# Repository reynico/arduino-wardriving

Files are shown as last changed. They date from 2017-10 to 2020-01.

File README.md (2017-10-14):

# ESP8266 based Arduino wardriving

## What is this?
A simple/cheap hardware + software setup to do wardriving trips and store as much information as we can on a SD card, using a small Arduino box.
Part of the datalogging code stolen from [Sparkfun](https://learn.sparkfun.com/tutorials/gps-logger-shield-hookup-guide/example-sketch-gps-serial-passthrough) guys

## What do we need?
* [$2.98](http://www.ebay.com/itm/222612803340) ESP8266 board (NodeMCU v3 works great)
* [$0.99](http://www.ebay.com/itm/261720518170) Arduino SD Card shield + SD card (a 10 minute trip could generate a 250KB file)
* [$4.21](http://www.ebay.com/itm/142233250679) Blox GY-NEO6MV2 GPS board
* [$3.07](http://www.ebay.com/itm/222311849398) HD44780 i2c LCD screen
* [$1.25](http://www.ebay.com/itm/332023213881) USB powerbank

## What does this do?
* Checks for a working SD Card
* Waits for GPS signal
* Collects all WiFi signals on 2.4Ghz on every (configurable) GPS sample
* Stores this information as a CSV file

## What does this doesn't do?
* This doesn't capture pcap files due power limitations
* This doesn't attack any network

## What does this need?
~~* A better/sorted insertion on CSV files to get rid of duplicate network entries~~ Fixed on d88815b43919bbf54e27a75a84c77be891900372
* Fix some race conditions
* A PCB design that I'm working on
* A better antenna for GPS and WiFi, that will help to speed up satellite lock-up and enlarge WiFi coverage

## What do you need to configure?
Nothing, but you can:
* Setup CS pin for SD card module on *ARDUINO_USD_CS* variable
* Change log file prefix and suffix on *LOG_FILE_PREFIX* and *LOG_FILE_SUFFIX*
* Remove or add columns to CSV datalog on *log_col_names*
* Define GPS log rate time on *LOG_RATE* (milliseconds)
* Define GPS TX/RX pins on *ARDUINO_GPS_RX* and *ARDUINO_GPS_TX*

## Electric setup
Electric setup has nothing special, there is a Fritzing diagram attached as well as a breadboard view of the setup


## Working examples
I did a small walking trip around my neighborhood, and put the collected data on a [Google MyMaps](https://www.google.com/maps/d/u/0/viewer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). Note that MyMaps has a limitation of 2000 entries of each CSV (or XML) file. I will try using Open street maps.


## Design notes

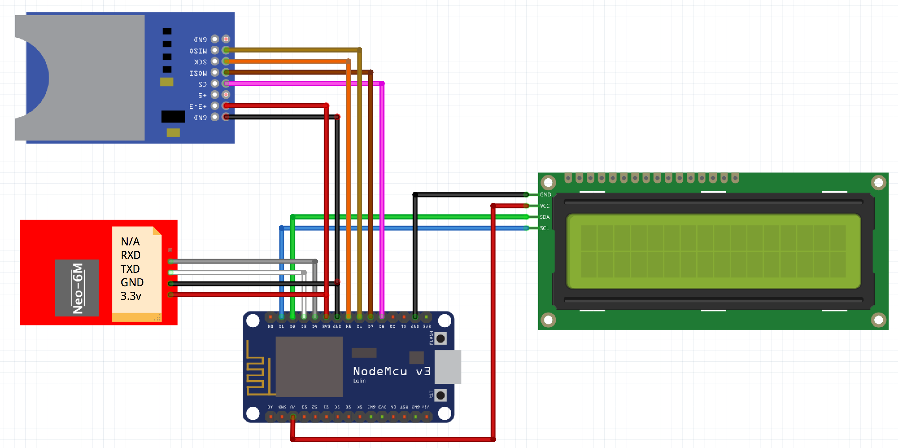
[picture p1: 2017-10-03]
breadboard.png

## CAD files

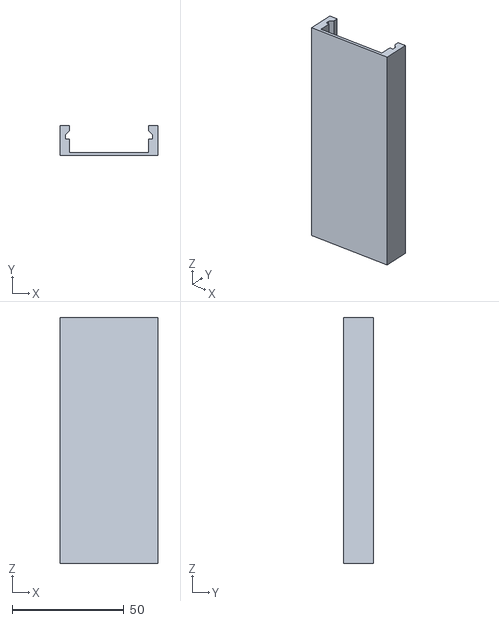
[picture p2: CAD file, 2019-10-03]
printed_case/Wardriving Case - B.stl
43.9 x 13.6 x 110.0

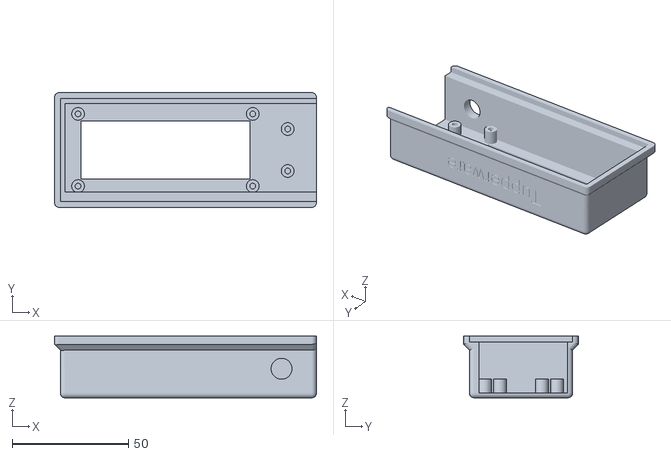
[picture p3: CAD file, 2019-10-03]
printed_case/Wardriving Case - A.stl
112.5 x 49.3 x 26.5

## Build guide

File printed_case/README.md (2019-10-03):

# 3D printed case
[Matias](https://instagram.com/punch.efi) designed and printed this case for the project.

## Finished product
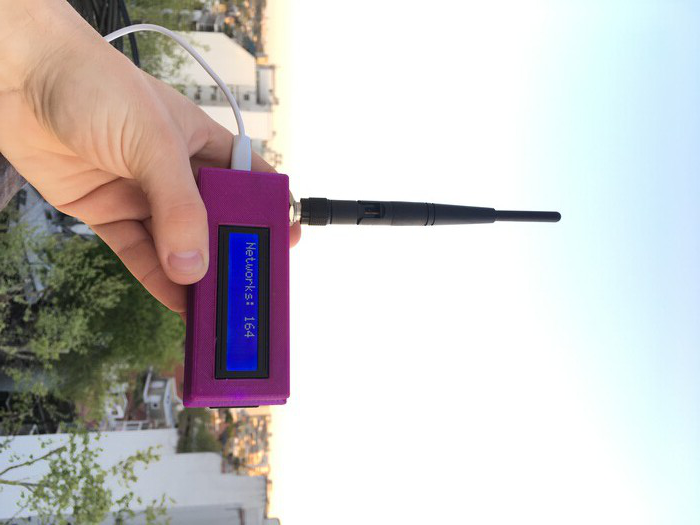
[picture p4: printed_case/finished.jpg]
finished


## Assembly view
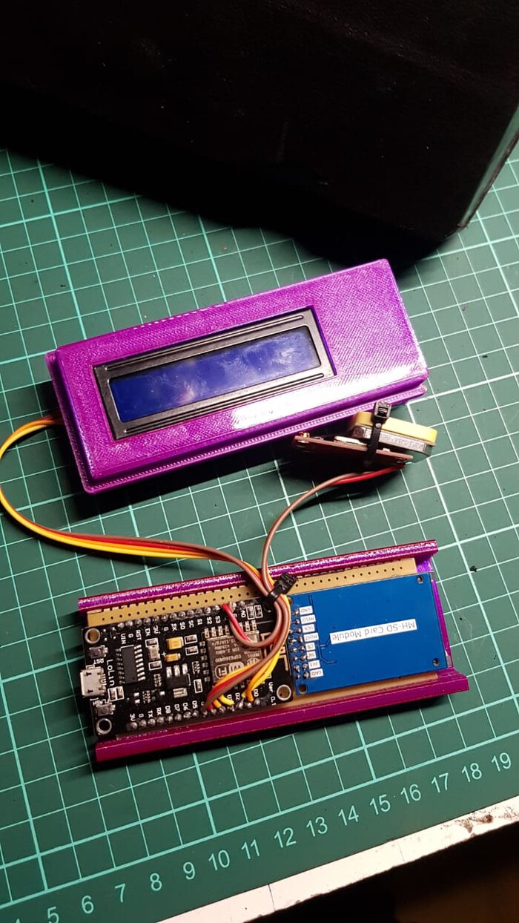
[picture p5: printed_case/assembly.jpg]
assembly


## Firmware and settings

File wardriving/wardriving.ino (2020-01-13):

#include <SD.h>
#include <SPI.h>
#include <Wire.h>
#include <TinyGPS++.h>
#include <SoftwareSerial.h>
#include <LiquidCrystal_I2C.h>
#include "ESP8266WiFi.h"

#define ARDUINO_USD_CS 15 // Pin D8
#define LOG_FILE_PREFIX "gpslog"
#define MAX_LOG_FILES 100
#define LOG_FILE_SUFFIX "csv"
#define LOG_COLUMN_COUNT 11
#define LOG_RATE 500

char logFileName[13];
int totalNetworks = 0;
unsigned long lastLog = 0;

const String wigleHeaderFileFormat = "WigleWifi-1.4,appRelease=2.26,model=Feather,release=0.0.0,device=arduinoWardriving,display=3fea5e7,board=esp8266,brand=Adafruit";
char * log_col_names[LOG_COLUMN_COUNT] = {
  "MAC", "SSID", "AuthMode", "FirstSeen", "Channel", "RSSI", "Latitude", "Longitude", "AltitudeMeters", "AccuracyMeters", "Type"
};

LiquidCrystal_I2C lcd(0x27, 16, 2);
TinyGPSPlus tinyGPS;
SoftwareSerial ss(2,0);

void setup() {
  Serial.begin(115200);
  ss.begin(9600);
  WiFi.mode(WIFI_STA);
  WiFi.disconnect();
  lcd.init();
  lcd.backlight();
  lcd.setCursor(0, 0);
  if (!SD.begin(ARDUINO_USD_CS)) {
    lcd.clear();
    lcd.setCursor(0,0);
    lcd.print("SD card error");
    Serial.println("Error initializing SD card.");
    while(true)
      delay(100);
  }
  lcd.clear();
  lcd.setCursor(0,0);
  lcd.print("SD card OK!");
  Serial.println("SD card OK!");
  delay(500);
  updateFileName();
  printHeader();
}

void loop() {
      if (tinyGPS.location.isValid()) {
        lookForNetworks();
        lcd.clear();
        lcd.setCursor(0, 0);
        lcd.print("Networks: ");
        lcd.print(totalNetworks);
      } else {
        Serial.print("Location invalid. Satellite count: ");
        Serial.println(tinyGPS.satellites.value());
        lcd.clear();
        lcd.setCursor(0, 0);
        lcd.print("GPS not locked");
        lcd.setCursor(0, 1);
        lcd.print("Sats: ");
        lcd.print(tinyGPS.satellites.value());
      }
    smartDelay(LOG_RATE);
}

static void smartDelay(unsigned long ms) {
  unsigned long start = millis();
  do {
    while (ss.available())
      tinyGPS.encode(ss.read());
  } while (millis() - start < ms);
}


void lookForNetworks() {
  int n = WiFi.scanNetworks();
  if (n == 0) {
    Serial.println("No networks found");
    lcd.clear();
    lcd.setCursor(0,0);
    lcd.println("No networks");
  } else {
    for (uint8_t i = 0; i <= n; ++i) {
      if ((isOnFile(WiFi.BSSIDstr(i)) == -1) && (WiFi.channel(i) > 0) && (WiFi.channel(i) < 15)) { //Avoid erroneous channels
        totalNetworks++;
        File logFile = SD.open(logFileName, FILE_WRITE);
        Serial.print("New network found ");
        Serial.println(WiFi.BSSIDstr(i));
        logFile.print(WiFi.BSSIDstr(i));
        logFile.print(',');
        String SSID = WiFi.SSID(i);
        // Commas in SSID brokes the csv file padding
        SSID.replace(",", ".");
        logFile.print(SSID);
        logFile.print(',');
        logFile.print(getEncryption(i));
        logFile.print(',');
        logFile.print(tinyGPS.date.year());
        logFile.print('-');
        logFile.print(tinyGPS.date.month());
        logFile.print('-');
        logFile.print(tinyGPS.date.day());
        logFile.print(' ');
        logFile.print(tinyGPS.time.hour());
        logFile.print(':');
        logFile.print(tinyGPS.time.minute());
        logFile.print(':');
        logFile.print(tinyGPS.time.second());
        logFile.print(',');
        logFile.print(WiFi.channel(i));
        logFile.print(',');
        logFile.print(WiFi.RSSI(i));
        logFile.print(',');
        logFile.print(tinyGPS.location.lat(), 6);
        logFile.print(',');
        logFile.print(tinyGPS.location.lng(), 6);
        logFile.print(',');
        logFile.print(tinyGPS.altitude.meters(), 1);
        logFile.print(',');
        logFile.print((tinyGPS.hdop.value(), 1));
        logFile.print(',');
        logFile.print("WIFI");
        logFile.println();
        logFile.close();
      }
    }
  }
}

String getEncryption(uint8_t network) {
  byte encryption = WiFi.encryptionType(network);
  switch (encryption) {
    case 2:
      return "[WPA-PSK-CCMP+TKIP][ESS]";
    case 5:
      return "[WEP][ESS]";
    case 4:
      return "[WPA2-PSK-CCMP+TKIP][ESS]";
    case 7:
      return "[ESS]";
    case 8:
      return "[WPA-PSK-CCMP+TKIP][WPA2-PSK-CCMP+TKIP][ESS]";
  }
}

int isOnFile(String mac) {
  File netFile = SD.open(logFileName);
  String currentNetwork;
  if (netFile) {
    while (netFile.available()) {
      currentNetwork = netFile.readStringUntil('\n');
      if (currentNetwork.indexOf(mac) != -1) {
        Serial.println("The network was already found");
        netFile.close();
        return currentNetwork.indexOf(mac);
      }
    }
    netFile.close();
    return currentNetwork.indexOf(mac);
  }
}

void printHeader() {
  File logFile = SD.open(logFileName, FILE_WRITE);
  if (logFile) {
    int i = 0;
    // logFile.println(wigleHeaderFileFormat); // comment out to disable Wigle header
    for (; i < LOG_COLUMN_COUNT; i++) {
      logFile.print(log_col_names[i]);
      if (i < LOG_COLUMN_COUNT - 1)
        logFile.print(',');
      else
        logFile.println();
    }
    logFile.close();
  }
}

void updateFileName() {
  int i = 0;
  for (; i < MAX_LOG_FILES; i++) {
    memset(logFileName, 0, strlen(logFileName));
    sprintf(logFileName, "%s%d.%s", LOG_FILE_PREFIX, i, LOG_FILE_SUFFIX);
    if (!SD.exists(logFileName)) {
      break;
    } else {
      Serial.print(logFileName);
      Serial.println(" exists");
    }
  }
  Serial.print("File name: ");
  Serial.println(logFileName);
}

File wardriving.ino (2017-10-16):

#include <SPI.h>
#include <SD.h>
#include <TinyGPS++.h>
#include "ESP8266WiFi.h"
#include <Wire.h>
#include <LiquidCrystal_I2C.h>
 
LiquidCrystal_I2C lcd(0x27, 16, 2);
#define ARDUINO_USD_CS 15 // Pin D8
#define LOG_FILE_PREFIX "gpslog"
#define MAX_LOG_FILES 100
#define LOG_FILE_SUFFIX "csv" 
char logFileName[13];
#define LOG_COLUMN_COUNT 13
char * log_col_names[LOG_COLUMN_COUNT] = {
  "Latitude", "Longitude", "Altitude", "Speed", "Course", "Date", "Time (UTC)", "Satellites", "SSID", "Power", "Channel", "Encryption", "BSSID"
};

#define LOG_RATE 2000
unsigned long lastLog = 0;

TinyGPSPlus tinyGPS;
#define GPS_BAUD 9600 // GPS module's default baud rate

#include <SoftwareSerial.h>
#define ARDUINO_GPS_RX 2 // Pin D4
#define ARDUINO_GPS_TX 0 // Pin D3
SoftwareSerial ssGPS(ARDUINO_GPS_TX, ARDUINO_GPS_RX);
#define gpsPort ssGPS 
int display = 1;

#define SerialMonitor Serial

void setup() {
  SerialMonitor.begin(115200);
  gpsPort.begin(GPS_BAUD);
  WiFi.mode(WIFI_STA);
  WiFi.disconnect();
  lcd.init();
  lcd.backlight();
  lcd.setCursor(0, 0);
  lcd.print("Setting up SD card.");
  SerialMonitor.println("Setting up SD card.");
  delay(200);
  lcd.clear();
  if (!SD.begin(ARDUINO_USD_CS)) {
    lcd.clear();
    lcd.setCursor(0, 1);
    lcd.print("Error initializing SD card.");
    SerialMonitor.println("Error initializing SD card.");
  }
  updateFileName();
  printHeader();
}

void loop() {
//  while (gpsPort.available() > 0)
//    tinyGPS.encode(gpsPort.read());
    
  if ((lastLog + LOG_RATE) <= millis()) {
    if (tinyGPS.location.isUpdated()) {
      if (logGPSData()) {
        SerialMonitor.print("GPS logged ");
        SerialMonitor.print(tinyGPS.location.lat(), 6);
        SerialMonitor.print(", ");
        SerialMonitor.println(tinyGPS.location.lng(), 6);
        SerialMonitor.print("Seen networks: ");
        SerialMonitor.println(countNetworks());
        if (display == 1) {
          lcd.clear();
          lcd.setCursor(0, 0);
          lcd.print("Lat: ");
          lcd.print(tinyGPS.location.lat(), 6);
          lcd.setCursor(0, 1);
          lcd.print("Lon: ");
          lcd.print(tinyGPS.location.lng(), 6);
          display = 0;
        } else {
          lcd.clear();
          lcd.setCursor(0, 0);
          lcd.print("Seen: ");
          lcd.print(countNetworks());
          lcd.setCursor(0, 1);
          lcd.print("networks");
          display = 1;
        }
        lastLog = millis();
      } else {
        lcd.setCursor(0, 1);
        SerialMonitor.println("Failed to log new GPS data.");
      }
    } else {
      lcd.setCursor(0, 0);
      lcd.print("No GPS data");
      lcd.setCursor(0, 1);
      lcd.print("Sats: ");
      lcd.print(tinyGPS.satellites.value());
      SerialMonitor.print("No GPS data. Sats: ");
      SerialMonitor.println(tinyGPS.satellites.value());
      delay(100);
    }
  }
  while (gpsPort.available())
    tinyGPS.encode(gpsPort.read());
}
int countNetworks() {
  File netFile = SD.open(logFileName);
  int networks = 0;
  if(netFile) {
    while(netFile.available()) {
      netFile.readStringUntil('\n');
      networks++;
    }
    netFile.close();
    if (networks == 0) {
      return networks;
    } else {
      return (networks-1); //Avoid header count
    }
  }
}
int isOnFile(String mac) {
  File netFile = SD.open(logFileName);
  String currentNetwork;
  if(netFile) {
    while(netFile.available()) {
      currentNetwork = netFile.readStringUntil('\n');
      if (currentNetwork.indexOf(mac) != -1) {
        SerialMonitor.println("The network was already found");
        netFile.close();
        return currentNetwork.indexOf(mac);
      }
    }
    netFile.close();
    return currentNetwork.indexOf(mac);
  }
}

byte logGPSData() {
  int n = WiFi.scanNetworks(); 
  if (n == 0) {
    SerialMonitor.println("no networks found");
  } else {
    for (uint8_t i = 1; i <= n; ++i) {
      if ((isOnFile(WiFi.BSSIDstr(i)) == -1) && (WiFi.channel(i) > 0) && (WiFi.channel(i) < 15)) { //Avoid erroneous channels
        File logFile = SD.open(logFileName, FILE_WRITE);
        SerialMonitor.println("New network found");
        logFile.print(tinyGPS.location.lat(), 6);
        logFile.print(',');
        logFile.print(tinyGPS.location.lng(), 6);
        logFile.print(',');
        logFile.print(tinyGPS.altitude.meters(), 1);
        logFile.print(',');
        logFile.print(tinyGPS.speed.kmph(), 1);
        logFile.print(',');
        logFile.print(tinyGPS.course.deg(), 1);
        logFile.print(',');
        logFile.print(tinyGPS.date.month());
        logFile.print('/');
        logFile.print(tinyGPS.date.day());
        logFile.print('/');
        logFile.print(tinyGPS.date.year());
        logFile.print(',');
        logFile.print(tinyGPS.time.hour());
        logFile.print(':');
        logFile.print(tinyGPS.time.minute());
        logFile.print(':');
        logFile.print(tinyGPS.time.second());
        logFile.print(',');
        int sat = tinyGPS.satellites.value();
        logFile.print(sat);
        logFile.print(',');
        logFile.print(WiFi.SSID(i));
        logFile.print(',');
        logFile.print(WiFi.RSSI(i));
        logFile.print(',');
        logFile.print(WiFi.channel(i));
        logFile.print(',');
        logFile.print(getEncryption(i));
        logFile.print(',');
        logFile.print(WiFi.BSSIDstr(i));
        logFile.println();
        logFile.close();
      }
    }
  }
}

void printHeader() {
  File logFile = SD.open(logFileName, FILE_WRITE);
  if (logFile) {
    int i = 0;
    for (; i < LOG_COLUMN_COUNT; i++) {
      logFile.print(log_col_names[i]);
      if (i < LOG_COLUMN_COUNT - 1)
        logFile.print(',');
      else
        logFile.println();
    }
    logFile.close();
  }
}

void updateFileName() {
  int i = 0;
  for (; i < MAX_LOG_FILES; i++) {
    memset(logFileName, 0, strlen(logFileName));
    sprintf(logFileName, "%s%d.%s", LOG_FILE_PREFIX, i, LOG_FILE_SUFFIX);
    if (!SD.exists(logFileName)) {
      break;
    } else {
      SerialMonitor.print(logFileName);
      SerialMonitor.println(" exists");
    }
  }
  SerialMonitor.print("File name: ");
  SerialMonitor.println(logFileName);
}

String getEncryption(uint8_t network) {
  byte encryption = WiFi.encryptionType(network);
  switch (encryption) {
    case 2:
      return "WPA (TKIP)";
    case 5:
      return "WEP";
    case 4:
      return "WPA (CCMP)";
    case 7:
      return "NONE";
    case 8:
      return "AUTO";
  }
}

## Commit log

2017-10-03 Added schematic and breadboard
    [schematic.fzz]
2017-10-13 Added check to avoid duplicate networks on list
    [wardriving.ino]
2017-10-15 Fixes to data display
    [wardriving.ino]
2017-10-16 Avoid erroneous channels during wardrive
    [wardriving.ino]
2018-04-03 Quick fix to serial monitor
    [wardriving.ino]
2018-04-04 Major refactor/rework on code
    [wardriving.ino]
2019-08-26 Several improvements on network storage, avoid checking network count from sd card, replace special characters on ssid, disable wigle header
    [wardriving.ino]
2019-10-03 Add printed case
    [Wardriving Case - A.stl, Wardriving Case - B.stl]
2020-01-13 fix loop error. Thanks farmerkz
    [wardriving.ino]
